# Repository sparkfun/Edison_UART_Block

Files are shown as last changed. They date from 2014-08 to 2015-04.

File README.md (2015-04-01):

SparkFun Edison UART Block
===========================

SparkFun Edison UART Block

[*SparkFun Edison UART Block(DEV-13040)*](https://www.sparkfun.com/products/13040)

The Console Basic expansion board delivers power to the Intel Edison while providing a simple console interface via a user's FTDI cable. This is the most minimal solution to get started using the Intel Edison. The Console Basic board can supply 4V and up to 500mA of current to power the Edison and any other expansion boards you may add to your stack. This power is passed through the VSYS line of the Edison.  This is a great board for low power applications that won't require constant console access.  By removing the FTDI USB-UART from the board, current consumption is minimal.  When the FTDI cable is not inserted, it will be necessary to provide external power to the board.

Repository Contents
------------------
* **/Hardware** - All Eagle design files (.brd, .sch)
* **/Production** -Test bed files and production panel files

License Information
------------------
The hardware is released under [Creative Commons ShareAlike 4.0 International](https://creativecommons.org/licenses/by-sa/4.0/).
The code is beerware; if you see me (or any other SparkFun employee) at the local, and you've found our code helpful, please buy us a round!

Distributed as-is; no warranty is given.

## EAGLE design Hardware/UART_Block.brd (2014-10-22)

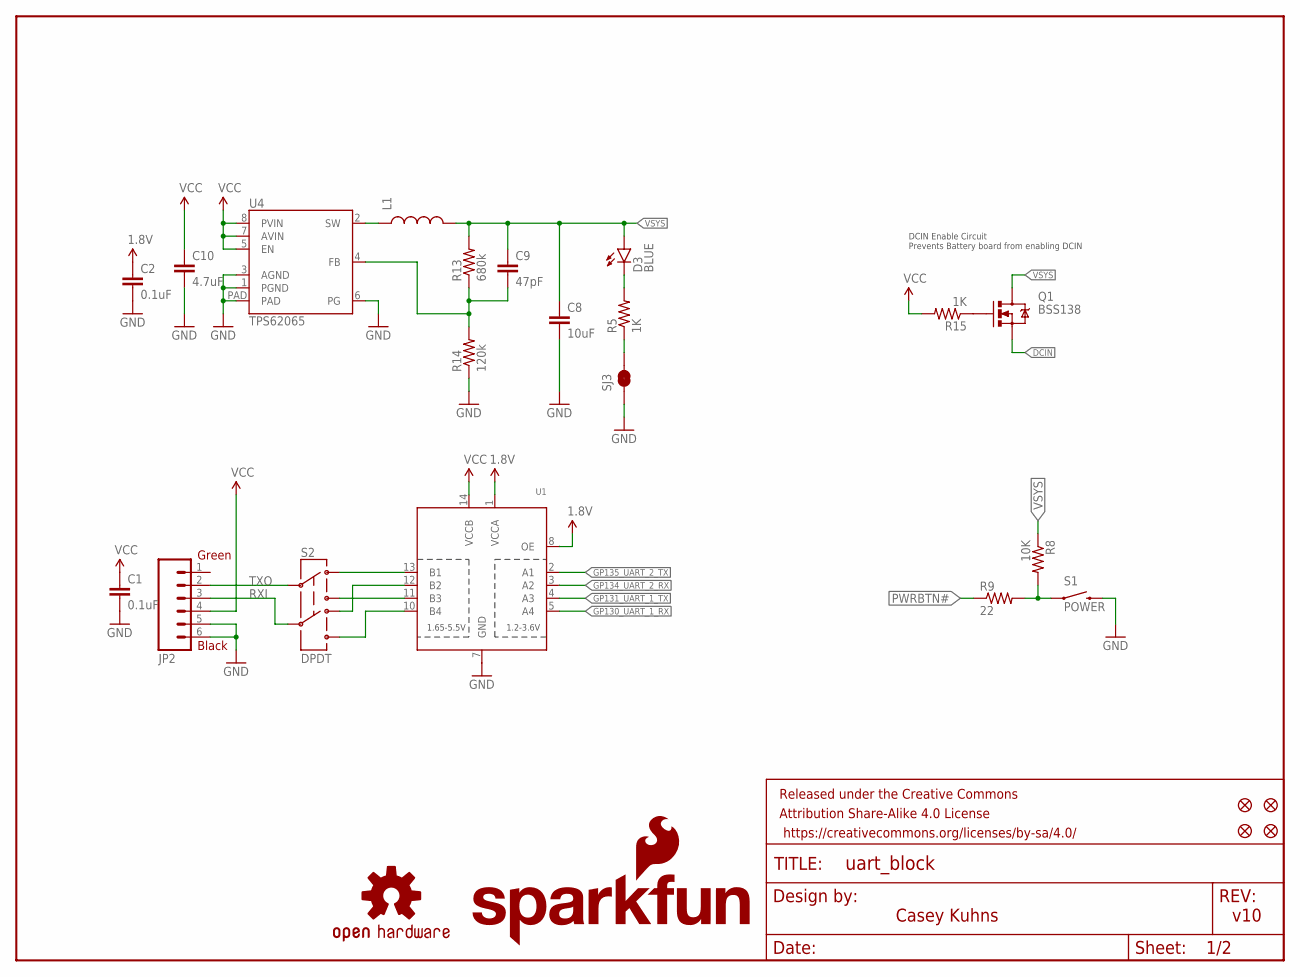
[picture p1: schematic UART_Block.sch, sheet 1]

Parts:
C1, C2: 0.1uF; 0603-CAP
C8: 10uF; 1206
C9: 47pF; 0603-CAP
C10: 4.7uF; 0603-CAP
D3: BLUE; LED-0603
FID1, FID2, FID3, FID4: FIDUCIAL1X2; FIDUCIAL-1X2
FRAME1: FRAME-LETTER; CREATIVE_COMMONS
JP2: M06SMD; 1X06-SMD
L1: INDUCTOR; INDUCTOR-SRP4020
LOGO1: SFE_LOGO_NAME_FLAME.1_INCH; SFE_LOGO_NAME_FLAME_.1
LOGO4: OSHW-LOGOS; OSHW-LOGO-S
Q1: BSS138; SOT23-3
R5, R15: 1K; 0603-RES
R8: 10K; 0603-RES
R9: 22; 0603-RES
R13: 680k; 0603-RES
R14: 120k; 0603-RES
S1: POWER; TACTILE_SWITCH-SMD-RIGHT-ANGLE
S2: DPDT; AYZ0202
SJ3: JUMPER-PAD-2-NC_BY_TRACE; PAD-JUMPER-2-NC_BY_TRACE_YES_SILK
U1: TXB0104PWRSOIC14; SO14
U4: TPS62065; WSON-8-PAD

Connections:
1.8V: C2.1, U1.1 (VCCA), U1.8 (OE); also elsewhere on the board
DCIN: Q1.2 (S); also elsewhere on the board
GND: C1.2, C2.2, C8.2, C10.2, JP2.5, JP2.6, R14.1, S1.2, SJ3.1, U1.7 (GND), U4.1 (PGND), U4.3 (AGND), U4.6 (PG), U4.PAD; also elsewhere on the board
GP130_UART_1_RX: U1.5 (A4); also elsewhere on the board
GP131_UART_1_TX: U1.4 (A3); also elsewhere on the board
GP134_UART_2_RX: U1.3 (A2); also elsewhere on the board
GP135_UART_2_TX: U1.2 (A1); also elsewhere on the board
unnamed: Q1.1 (G), R15.1
unnamed: D3.C, R5.2
unnamed: R5.1, SJ3.2
unnamed: R8.2, R9.2, S1.1
unnamed: C9.2, R13.1, R14.2, U4.4 (FB)
unnamed: L1.P$1 (1), U4.2 (SW)
PWRBTN#: R9.1; also elsewhere on the board
RXI: JP2.3, S2.5
TXO: JP2.2, S2.2
UART1RX: S2.6, U1.10 (B4)
UART1TX: S2.3, U1.11 (B3)
UART2RX: S2.4, U1.12 (B2)
UART2TX: S2.1, U1.13 (B1)
VCC: C1.1, C10.1, JP2.4, R15.2, U1.14 (VCCB), U4.5 (EN), U4.7 (AVIN), U4.8 (PVIN)
VSYS: C8.1, C9.1, D3.A, L1.P$2 (2), Q1.3 (D), R8.1, R13.2; also elsewhere on the board

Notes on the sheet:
Black
Green
v10
Casey Kuhns
DCIN Enable Circuit Prevents Battery board from enabling DCIN

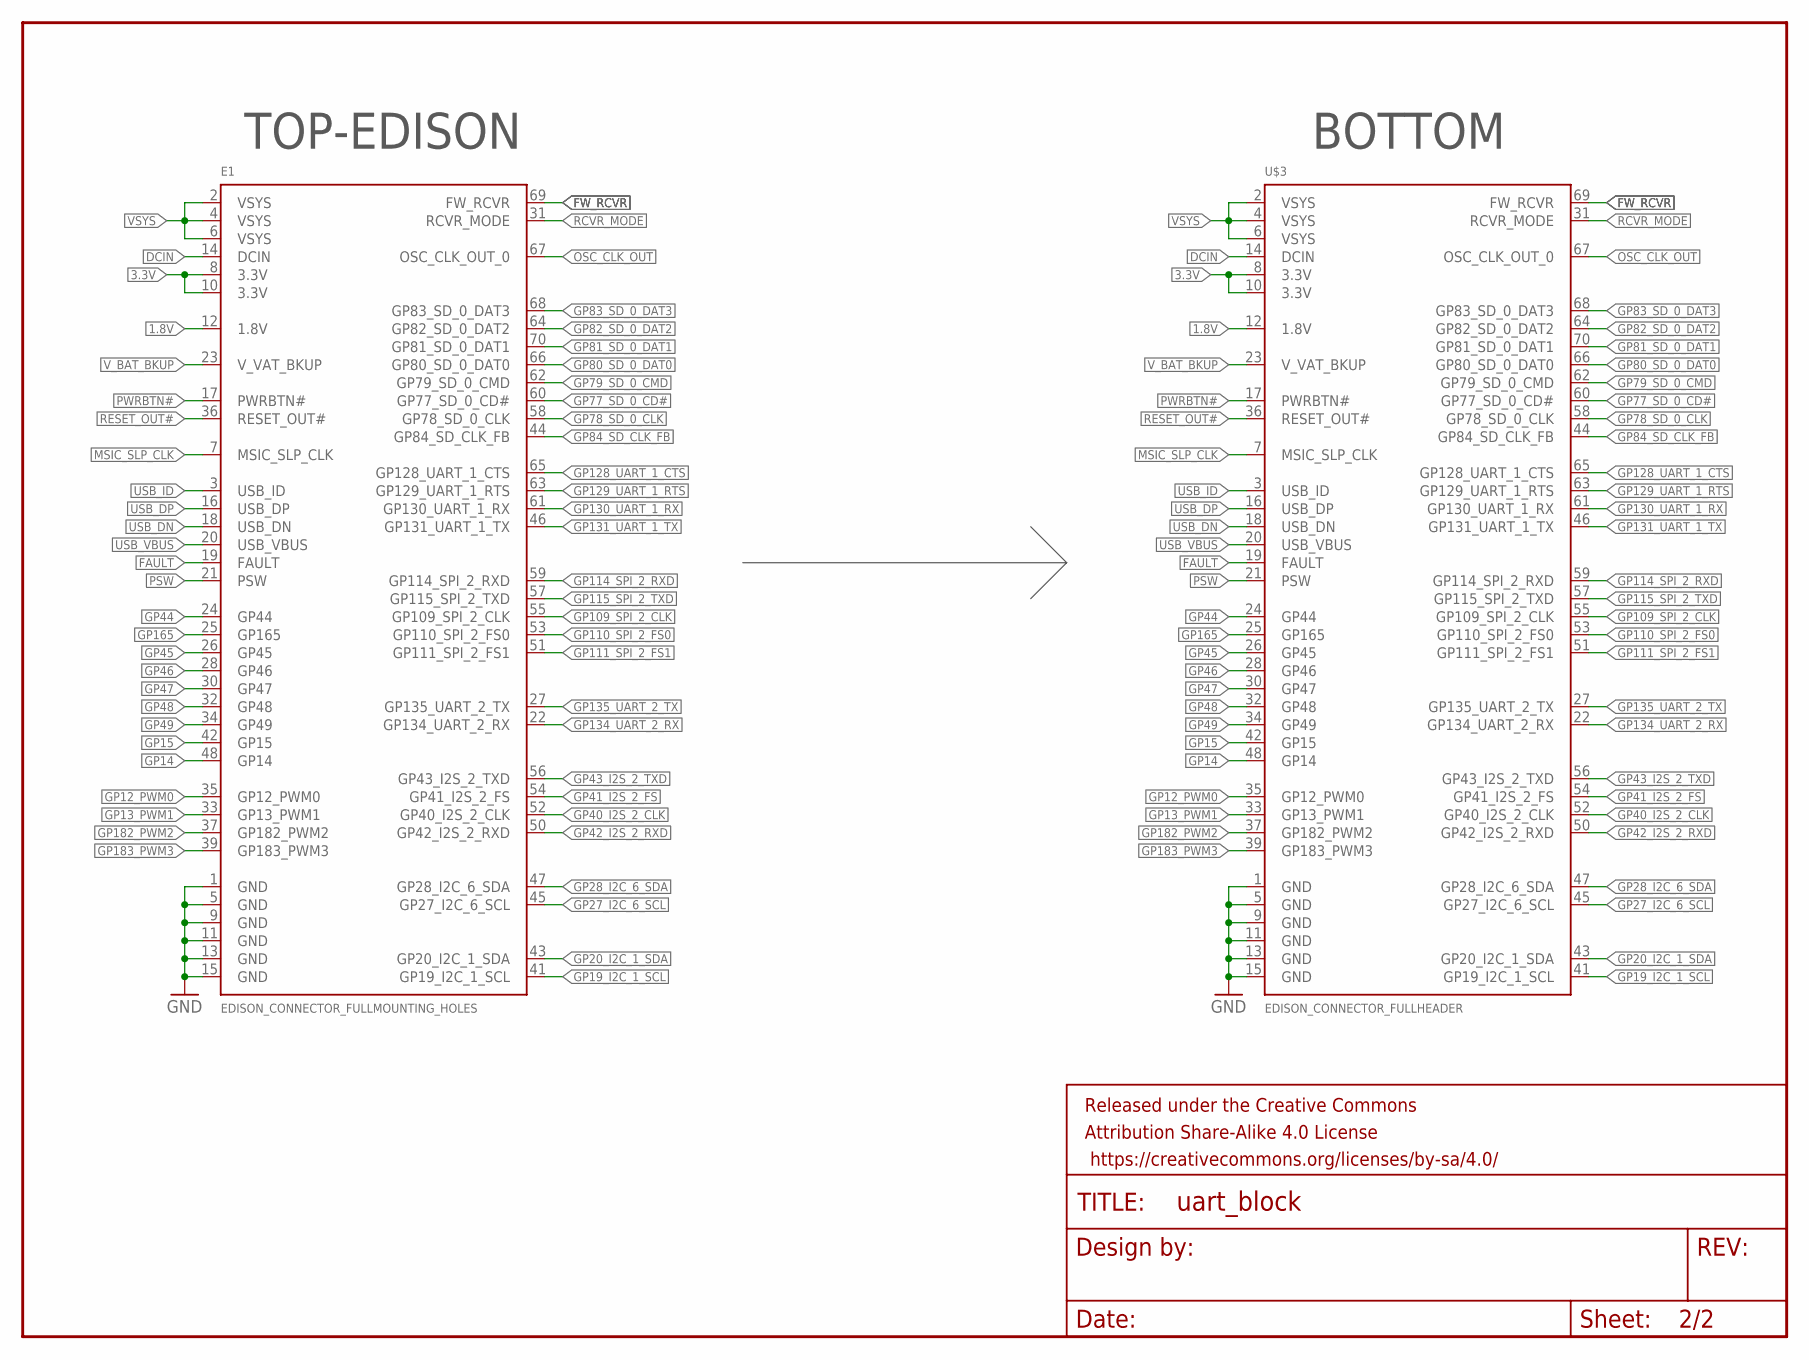
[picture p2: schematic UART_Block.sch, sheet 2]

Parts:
E1: EDISON_CONNECTOR_FULLMOUNTING_HOLES; EDISON_DAUGHTER
FRAME2: FRAME-LETTER; CREATIVE_COMMONS
U$3: EDISON_CONNECTOR_FULLHEADER; DF40C-70DP-0.4(51)

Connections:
1.8V: E1.12 (1.8V), U$3.12 (1.8V); also elsewhere on the board
3.3V: E1.8 (3.3V), E1.10 (3.3V), U$3.8 (3.3V), U$3.10 (3.3V)
DCIN: E1.14 (DCIN), U$3.14 (DCIN); also elsewhere on the board
FAULT: E1.19 (FAULT), U$3.19 (FAULT)
FW_RCVR: E1.69 (FW_RCVR), U$3.69 (FW_RCVR)
GND: E1.1 (GND), E1.5 (GND), E1.9 (GND), E1.11 (GND), E1.13 (GND), E1.15 (GND), U$3.1 (GND), U$3.5 (GND), U$3.9 (GND), U$3.11 (GND), U$3.13 (GND), U$3.15 (GND); also elsewhere on the board
GP12_PWM0: E1.35 (GP12_PWM0), U$3.35 (GP12_PWM0)
GP13_PWM1: E1.33 (GP13_PWM1), U$3.33 (GP13_PWM1)
GP14: E1.48 (GP14), U$3.48 (GP14)
GP15: E1.42 (GP15), U$3.42 (GP15)
GP19_I2C_1_SCL: E1.41 (GP19_I2C_1_SCL), U$3.41 (GP19_I2C_1_SCL)
GP20_I2C_1_SDA: E1.43 (GP20_I2C_1_SDA), U$3.43 (GP20_I2C_1_SDA)
GP27_I2C_6_SCL: E1.45 (GP27_I2C_6_SCL), U$3.45 (GP27_I2C_6_SCL)
GP28_I2C_6_SDA: E1.47 (GP28_I2C_6_SDA), U$3.47 (GP28_I2C_6_SDA)
GP40_I2S_2_CLK: E1.52 (GP40_I2S_2_CLK), U$3.52 (GP40_I2S_2_CLK)
GP41_I2S_2_FS: E1.54 (GP41_I2S_2_FS), U$3.54 (GP41_I2S_2_FS)
GP42_I2S_2_RXD: E1.50 (GP42_I2S_2_RXD), U$3.50 (GP42_I2S_2_RXD)
GP43_I2S_2_TXD: E1.56 (GP43_I2S_2_TXD), U$3.56 (GP43_I2S_2_TXD)
GP44: E1.24 (GP44), U$3.24 (GP44)
GP45: E1.26 (GP45), U$3.26 (GP45)
GP46: E1.28 (GP46), U$3.28 (GP46)
GP47: E1.30 (GP47), U$3.30 (GP47)
GP48: E1.32 (GP48), U$3.32 (GP48)
GP49: E1.34 (GP49), U$3.34 (GP49)
GP77_SD_0_CD#: E1.60 (GP77_SD_0_CD#), U$3.60 (GP77_SD_0_CD#)
GP78_SD_0_CLK: E1.58 (GP78_SD_0_CLK), U$3.58 (GP78_SD_0_CLK)
GP79_SD_0_CMD: E1.62 (GP79_SD_0_CMD), U$3.62 (GP79_SD_0_CMD)
GP80_SD_0_DAT0: E1.66 (GP80_SD_0_DAT0), U$3.66 (GP80_SD_0_DAT0)
GP81_SD_0_DAT1: E1.70 (GP81_SD_0_DAT1), U$3.70 (GP81_SD_0_DAT1)
GP82_SD_0_DAT2: E1.64 (GP82_SD_0_DAT2), U$3.64 (GP82_SD_0_DAT2)
GP83_SD_0_DAT3: E1.68 (GP83_SD_0_DAT3), U$3.68 (GP83_SD_0_DAT3)
GP84_SD_CLK_FB: E1.44 (GP84_SD_CLK_FB), U$3.44 (GP84_SD_CLK_FB)
GP109_SPI_2_CLK: E1.55 (GP109_SPI_2_CLK), U$3.55 (GP109_SPI_2_CLK)
GP110_SPI_2_FS0: E1.53 (GP110_SPI_2_FS0), U$3.53 (GP110_SPI_2_FS0)
GP111_SPI_2_FS1: E1.51 (GP111_SPI_2_FS1), U$3.51 (GP111_SPI_2_FS1)
GP114_SPI_2_RXD: E1.59 (GP114_SPI_2_RXD), U$3.59 (GP114_SPI_2_RXD)
GP115_SPI_2_TXD: E1.57 (GP115_SPI_2_TXD), U$3.57 (GP115_SPI_2_TXD)
GP128_UART_1_CTS: E1.65 (GP128_UART_1_CTS), U$3.65 (GP128_UART_1_CTS)
GP129_UART_1_RTS: E1.63 (GP129_UART_1_RTS), U$3.63 (GP129_UART_1_RTS)
GP130_UART_1_RX: E1.61 (GP130_UART_1_RX), U$3.61 (GP130_UART_1_RX); also elsewhere on the board
GP131_UART_1_TX: E1.46 (GP131_UART_1_TX), U$3.46 (GP131_UART_1_TX); also elsewhere on the board
GP134_UART_2_RX: E1.22 (GP134_UART_2_RX), U$3.22 (GP134_UART_2_RX); also elsewhere on the board
GP135_UART_2_TX: E1.27 (GP135_UART_2_TX), U$3.27 (GP135_UART_2_TX); also elsewhere on the board
GP165: E1.25 (GP165), U$3.25 (GP165)
GP182_PWM2: E1.37 (GP182_PWM2), U$3.37 (GP182_PWM2)
GP183_PWM3: E1.39 (GP183_PWM3), U$3.39 (GP183_PWM3)
MSIC_SLP_CLK: E1.7 (MSIC_SLP_CLK), U$3.7 (MSIC_SLP_CLK)
OSC_CLK_OUT: E1.67 (OSC_CLK_OUT_0), U$3.67 (OSC_CLK_OUT_0)
PSW: E1.21 (PSW), U$3.21 (PSW)
PWRBTN#: E1.17 (PWRBTN#), U$3.17 (PWRBTN#); also elsewhere on the board
RCVR_MODE: E1.31 (RCVR_MODE), U$3.31 (RCVR_MODE)
RESET_OUT#: E1.36 (RESET_OUT#), U$3.36 (RESET_OUT#)
USB_DN: E1.18 (USB_DN), U$3.18 (USB_DN)
USB_DP: E1.16 (USB_DP), U$3.16 (USB_DP)
USB_ID: E1.3 (USB_ID), U$3.3 (USB_ID)
USB_VBUS: E1.20 (USB_VBUS), U$3.20 (USB_VBUS)
VSYS: E1.2 (VSYS), E1.4 (VSYS), E1.6 (VSYS), U$3.2 (VSYS), U$3.4 (VSYS), U$3.6 (VSYS); also elsewhere on the board
V_BAT_BKUP: E1.23 (V_VAT_BKUP), U$3.23 (V_VAT_BKUP)

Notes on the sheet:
TOP-EDISON
BOTTOM

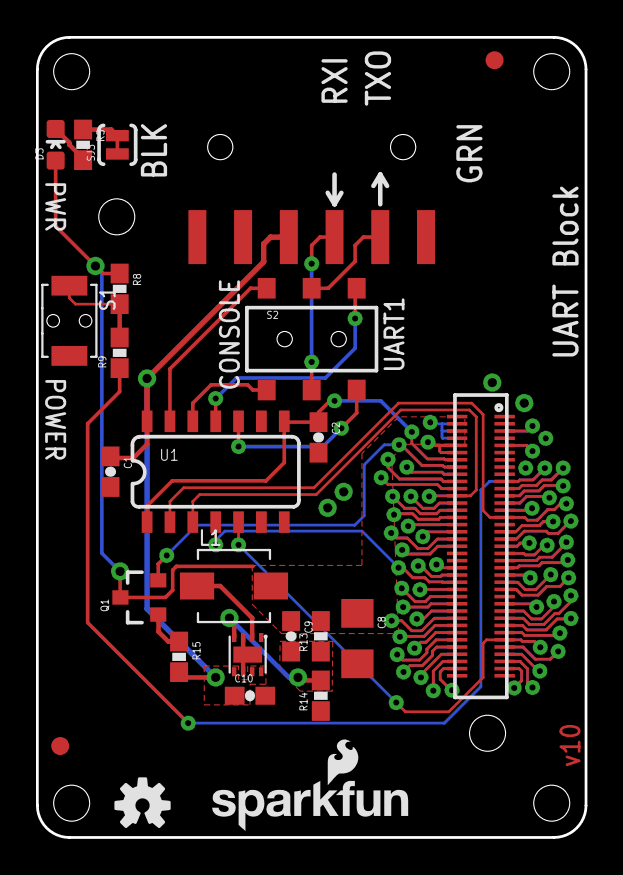
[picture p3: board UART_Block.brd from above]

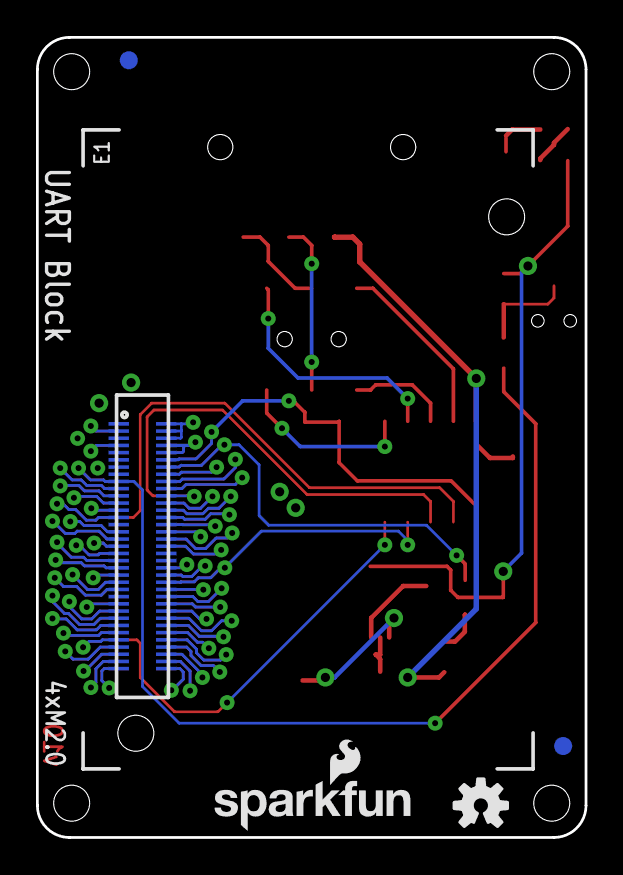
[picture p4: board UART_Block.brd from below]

Board: 2 copper layers, 30.5 x 44.5 mm, 32 parts (6 on the bottom side), 71 nets.

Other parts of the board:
LOGO2: OSHW-LOGOS; OSHW-LOGO-S
LOGO3: SFE_LOGO_NAME_FLAME.1_INCH; SFE_LOGO_NAME_FLAME_.1

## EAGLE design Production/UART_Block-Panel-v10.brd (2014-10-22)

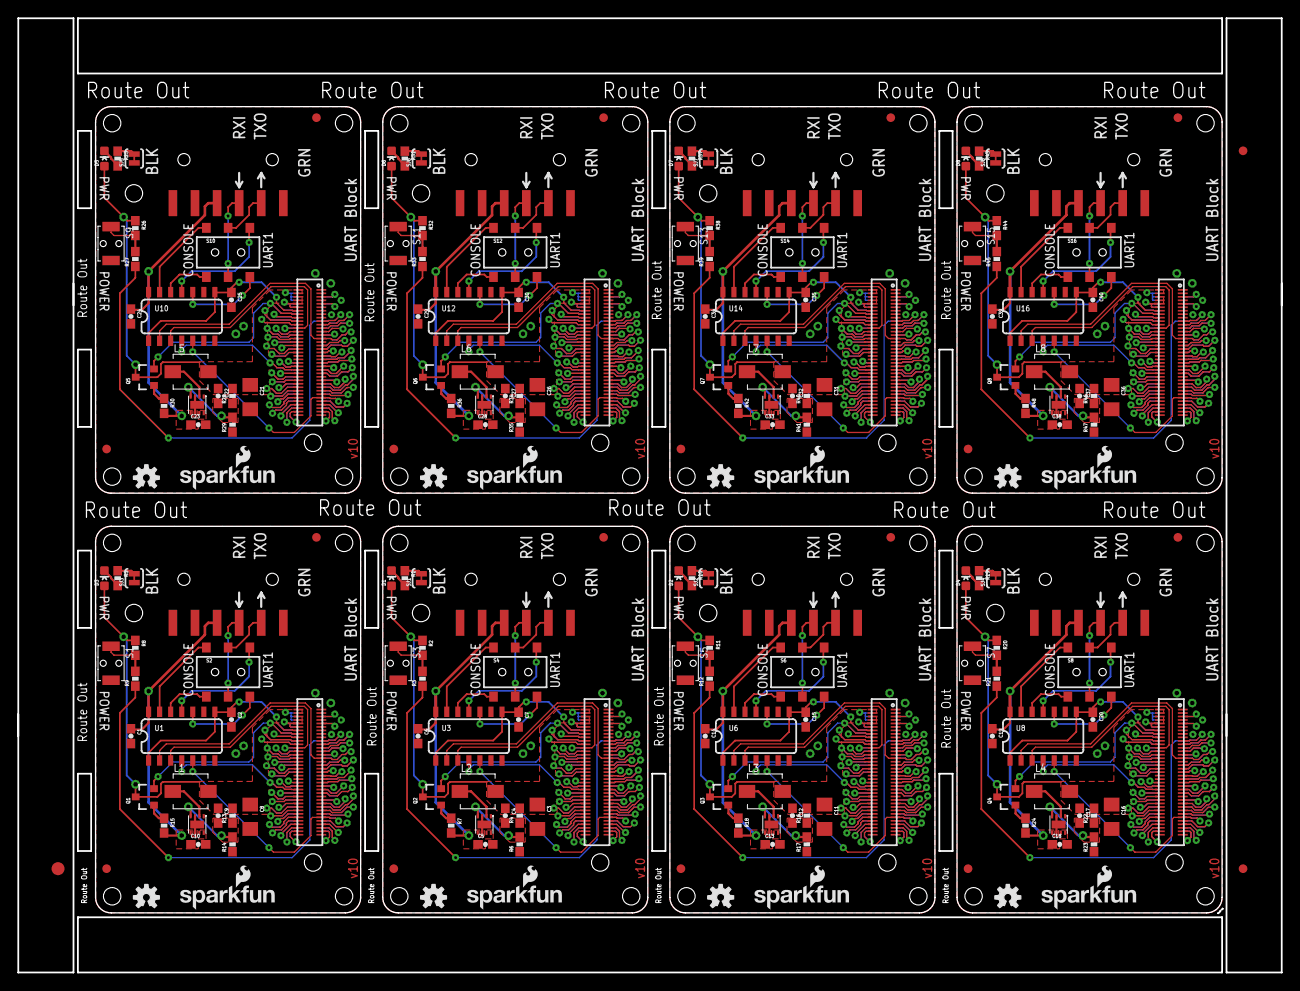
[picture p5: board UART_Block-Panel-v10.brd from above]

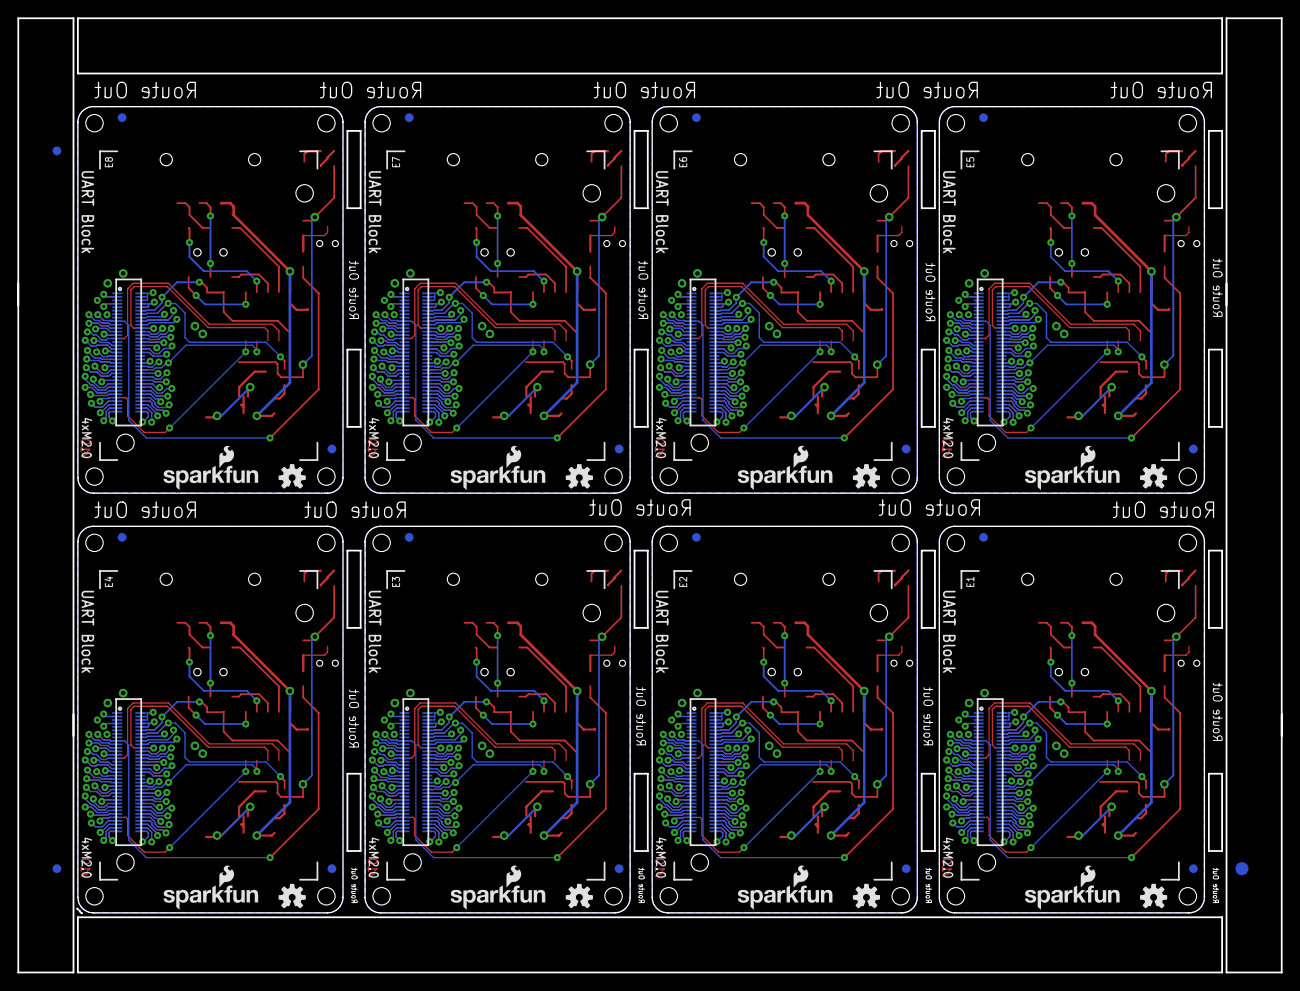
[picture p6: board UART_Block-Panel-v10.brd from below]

Board: 2 copper layers, 145.3 x 109.7 mm, 246 parts (51 on the bottom side), 568 nets.

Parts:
C1, C2, C6, C7, C14, C15, C19, C20, C24, C25, C29, C30, C34, C35, C39, C40: 0.1uF; 0603-CAP
C3, C8, C11, C16, C21, C26, C31, C36: 10uF; 1206
C4, C9, C12, C17, C22, C27, C32, C37: 47pF; 0603-CAP
C5, C10, C13, C18, C23, C28, C33, C38: 4.7uF; 0603-CAP
D1, D2, D3, D4, D5, D6, D7, D8: BLUE; LED-0603
E1, E2, E3, E4, E5, E6, E7, E8: EDISON_CONNECTOR_FULLMOUNTING_HOLES; EDISON_DAUGHTER
E$1, E$2: FIDUCIAL-1.5X3
E$3, E$4, E$5, E$6: FIDUCIAL-1X2
FID1, FID2, FID3, FID4, FID5, FID6, FID7, FID8, FID9, FID10, FID11, FID12, FID13, FID14, FID15, FID16, FID17, FID18, FID19, FID20, FID21, FID22, FID23, FID24, FID25, FID26, FID27, FID28, FID29, FID30, FID31, FID32: FIDUCIAL1X2; FIDUCIAL-1X2
JP1, JP2, JP3, JP4, JP5, JP6, JP7, JP8: 1X06-SMD
L1, L2, L3, L4, L5, L6, L7, L8: INDUCTOR-SRP4020
LOGO1, LOGO3, LOGO6, LOGO7, LOGO10, LOGO11, LOGO14, LOGO15, LOGO18, LOGO19, LOGO22, LOGO23, LOGO26, LOGO27, LOGO30, LOGO31: SFE_LOGO_NAME_FLAME.1_INCH; SFE_LOGO_NAME_FLAME_.1
LOGO2, LOGO4, LOGO5, LOGO8, LOGO9, LOGO12, LOGO13, LOGO16, LOGO17, LOGO20, LOGO21, LOGO24, LOGO25, LOGO28, LOGO29, LOGO32: OSHW-LOGOS; OSHW-LOGO-S
Q1, Q2, Q3, Q4, Q5, Q6, Q7, Q8: BSS138; SOT23-3
R1, R5, R7, R10, R15, R18, R19, R24, R25, R30, R31, R36, R37, R42, R43, R48: 1K; 0603-RES
R2, R8, R11, R20, R26, R32, R38, R44: 10K; 0603-RES
R3, R9, R12, R21, R27, R33, R39, R45: 22; 0603-RES
R4, R13, R16, R22, R28, R34, R40, R46: 680k; 0603-RES
R6, R14, R17, R23, R29, R35, R41, R47: 120k; 0603-RES
S1, S3, S5, S7, S9, S11, S13, S15: POWER; TACTILE_SWITCH-SMD-RIGHT-ANGLE
S2, S4, S6, S8, S10, S12, S14, S16: DPDT; AYZ0202
SJ1, SJ2, SJ3, SJ4, SJ5, SJ6, SJ7, SJ8: JUMPER-PAD-2-NC_BY_TRACE; PAD-JUMPER-2-NC_BY_TRACE_YES_SILK
U1, U3, U6, U8, U10, U12, U14, U16: SO14
U2, U4, U5, U7, U9, U11, U13, U15: TPS62065; WSON-8-PAD
U$1, U$2, U$3, U$4, U$5, U$6, U$7, U$8: EDISON_CONNECTOR_FULLHEADER; DF40C-70DP-0.4(51)

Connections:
1.8V: C2.1, E1.12, U1.1, U1.8, U$3.12
1.8V1: C7.1, E2.12, U3.1, U3.8, U$1.12
1.8V2: C15.1, E3.12, U6.1, U6.8, U$2.12
1.8V3: C20.1, E4.12, U8.1, U8.8, U$4.12
1.8V4: C25.1, E5.12, U10.1, U10.8, U$5.12
1.8V5: C30.1, E6.12, U12.1, U12.8, U$6.12
1.8V6: C35.1, E7.12, U14.1, U14.8, U$7.12
1.8V7: C40.1, E8.12, U16.1, U16.8, U$8.12
3.3V: E1.8, E1.10, U$3.8, U$3.10
3.3V1: E2.8, E2.10, U$1.8, U$1.10
3.3V2: E3.8, E3.10, U$2.8, U$2.10
3.3V3: E4.8, E4.10, U$4.8, U$4.10
3.3V4: E5.8, E5.10, U$5.8, U$5.10
3.3V5: E6.8, E6.10, U$6.8, U$6.10
3.3V6: E7.8, E7.10, U$7.8, U$7.10
3.3V7: E8.8, E8.10, U$8.8, U$8.10
DCIN: E1.14, Q1.2, U$3.14
DCIN1: E2.14, Q2.2, U$1.14
DCIN2: E3.14, Q3.2, U$2.14
DCIN3: E4.14, Q4.2, U$4.14
DCIN4: E5.14, Q5.2, U$5.14
DCIN5: E6.14, Q6.2, U$6.14
DCIN6: E7.14, Q7.2, U$7.14
DCIN7: E8.14, Q8.2, U$8.14
FAULT: E1.19, U$3.19
FAULT1: E2.19, U$1.19
FAULT2: E3.19, U$2.19
FAULT3: E4.19, U$4.19
FAULT4: E5.19, U$5.19
FAULT5: E6.19, U$6.19
FAULT6: E7.19, U$7.19
FAULT7: E8.19, U$8.19
FW_RCVR: E1.69, U$3.69
FW_RCVR1: E2.69, U$1.69
FW_RCVR2: E3.69, U$2.69
FW_RCVR3: E4.69, U$4.69
FW_RCVR4: E5.69, U$5.69
FW_RCVR5: E6.69, U$6.69
FW_RCVR6: E7.69, U$7.69
FW_RCVR7: E8.69, U$8.69
GND: C1.2, C2.2, C8.2, C10.2, E1.1, E1.5, E1.9, E1.11, E1.13, E1.15, JP2.5, JP2.6, R14.1, S1.2, SJ3.1, U1.7, U4.1, U4.3, U4.6, U4.PAD, U$3.1, U$3.5, U$3.9, U$3.11, U$3.13, U$3.15
GND1: C3.2, C5.2, C6.2, C7.2, E2.1, E2.5, E2.9, E2.11, E2.13, E2.15, JP1.5, JP1.6, R6.1, S3.2, SJ1.1, U2.1, U2.3, U2.6, U2.PAD, U3.7, U$1.1, U$1.5, U$1.9, U$1.11, U$1.13, U$1.15
GND2: C11.2, C13.2, C14.2, C15.2, E3.1, E3.5, E3.9, E3.11, E3.13, E3.15, JP3.5, JP3.6, R17.1, S5.2, SJ2.1, U5.1, U5.3, U5.6, U5.PAD, U6.7, U$2.1, U$2.5, U$2.9, U$2.11, U$2.13, U$2.15
GND3: C16.2, C18.2, C19.2, C20.2, E4.1, E4.5, E4.9, E4.11, E4.13, E4.15, JP4.5, JP4.6, R23.1, S7.2, SJ4.1, U7.1, U7.3, U7.6, U7.PAD, U8.7, U$4.1, U$4.5, U$4.9, U$4.11, U$4.13, U$4.15
GND4: C21.2, C23.2, C24.2, C25.2, E5.1, E5.5, E5.9, E5.11, E5.13, E5.15, JP5.5, JP5.6, R29.1, S9.2, SJ5.1, U9.1, U9.3, U9.6, U9.PAD, U10.7, U$5.1, U$5.5, U$5.9, U$5.11, U$5.13, U$5.15
GND5: C26.2, C28.2, C29.2, C30.2, E6.1, E6.5, E6.9, E6.11, E6.13, E6.15, JP6.5, JP6.6, R35.1, S11.2, SJ6.1, U11.1, U11.3, U11.6, U11.PAD, U12.7, U$6.1, U$6.5, U$6.9, U$6.11, U$6.13, U$6.15
GND6: C31.2, C33.2, C34.2, C35.2, E7.1, E7.5, E7.9, E7.11, E7.13, E7.15, JP7.5, JP7.6, R41.1, S13.2, SJ7.1, U13.1, U13.3, U13.6, U13.PAD, U14.7, U$7.1, U$7.5, U$7.9, U$7.11, U$7.13, U$7.15
GND7: C36.2, C38.2, C39.2, C40.2, E8.1, E8.5, E8.9, E8.11, E8.13, E8.15, JP8.5, JP8.6, R47.1, S15.2, SJ8.1, U15.1, U15.3, U15.6, U15.PAD, U16.7, U$8.1, U$8.5, U$8.9, U$8.11, U$8.13, U$8.15
GP1: E2.48, U$1.48
GP2: E2.42, U$1.42
GP3: E2.34, U$1.34
GP4: E2.32, U$1.32
GP5: E2.30, U$1.30
GP6: E2.28, U$1.28
GP7: E2.26, U$1.26
GP8: E2.25, U$1.25
GP9: E2.24, U$1.24
GP10: E3.48, U$2.48
GP11: E3.42, U$2.42
GP12: E3.34, U$2.34
GP12_PWM0: E1.35, U$3.35
GP12_PWM1: E2.35, U$1.35
GP12_PWM2: E3.35, U$2.35
GP12_PWM3: E4.35, U$4.35
GP12_PWM4: E5.35, U$5.35
GP12_PWM5: E6.35, U$6.35
GP12_PWM6: E7.35, U$7.35
GP12_PWM7: E8.35, U$8.35
GP13: E3.32, U$2.32
GP13_PWM1: E1.33, U$3.33
GP13_PWM2: E2.33, U$1.33
GP13_PWM3: E3.33, U$2.33
GP13_PWM4: E4.33, U$4.33
GP13_PWM5: E5.33, U$5.33
GP13_PWM6: E6.33, U$6.33
GP13_PWM7: E7.33, U$7.33
GP13_PWM8: E8.33, U$8.33
GP14: E1.48, U$3.48
GP15: E1.42, U$3.42
GP16: E3.30, U$2.30
GP17: E3.28, U$2.28
GP18: E3.26, U$2.26
GP19: E3.25, U$2.25
GP19_I2C_1_SCL: E1.41, U$3.41
GP19_I2C_1_SCL1: E2.41, U$1.41
GP19_I2C_1_SCL2: E3.41, U$2.41
GP19_I2C_1_SCL3: E4.41, U$4.41
GP19_I2C_1_SCL4: E5.41, U$5.41
GP19_I2C_1_SCL5: E6.41, U$6.41
GP19_I2C_1_SCL6: E7.41, U$7.41
GP19_I2C_1_SCL7: E8.41, U$8.41
GP20: E3.24, U$2.24
GP20_I2C_1_SDA: E1.43, U$3.43
GP20_I2C_1_SDA1: E2.43, U$1.43
GP20_I2C_1_SDA2: E3.43, U$2.43
GP20_I2C_1_SDA3: E4.43, U$4.43
GP20_I2C_1_SDA4: E5.43, U$5.43
GP20_I2C_1_SDA5: E6.43, U$6.43
GP20_I2C_1_SDA6: E7.43, U$7.43
GP20_I2C_1_SDA7: E8.43, U$8.43
GP21: E4.48, U$4.48
GP22: E4.42, U$4.42
GP23: E4.34, U$4.34
GP24: E4.32, U$4.32
GP25: E4.30, U$4.30
GP26: E4.28, U$4.28
GP27: E4.26, U$4.26
GP27_I2C_6_SCL: E1.45, U$3.45
GP27_I2C_6_SCL1: E2.45, U$1.45
GP27_I2C_6_SCL2: E3.45, U$2.45
GP27_I2C_6_SCL3: E4.45, U$4.45
GP27_I2C_6_SCL4: E5.45, U$5.45
GP27_I2C_6_SCL5: E6.45, U$6.45
GP27_I2C_6_SCL6: E7.45, U$7.45
GP27_I2C_6_SCL7: E8.45, U$8.45
GP28: E4.25, U$4.25
GP28_I2C_6_SDA: E1.47, U$3.47
GP28_I2C_6_SDA1: E2.47, U$1.47
GP28_I2C_6_SDA2: E3.47, U$2.47
GP28_I2C_6_SDA3: E4.47, U$4.47
GP28_I2C_6_SDA4: E5.47, U$5.47
GP28_I2C_6_SDA5: E6.47, U$6.47
GP28_I2C_6_SDA6: E7.47, U$7.47
GP28_I2C_6_SDA7: E8.47, U$8.47
GP29: E4.24, U$4.24
GP30: E5.48, U$5.48
GP31: E5.42, U$5.42
GP32: E5.34, U$5.34
GP33: E5.32, U$5.32
GP34: E5.30, U$5.30
GP35: E5.28, U$5.28
GP36: E5.26, U$5.26
GP37: E5.25, U$5.25
GP38: E5.24, U$5.24
GP39: E6.48, U$6.48
GP40: E6.42, U$6.42
GP40_I2S_2_CLK: E1.52, U$3.52
GP40_I2S_2_CLK1: E2.52, U$1.52
GP40_I2S_2_CLK2: E3.52, U$2.52
GP40_I2S_2_CLK3: E4.52, U$4.52
GP40_I2S_2_CLK4: E5.52, U$5.52
GP40_I2S_2_CLK5: E6.52, U$6.52
GP40_I2S_2_CLK6: E7.52, U$7.52
GP40_I2S_2_CLK7: E8.52, U$8.52
GP41: E6.34, U$6.34
GP41_I2S_2_FS: E1.54, U$3.54
GP41_I2S_2_FS1: E2.54, U$1.54
GP41_I2S_2_FS2: E3.54, U$2.54
GP41_I2S_2_FS3: E4.54, U$4.54
GP41_I2S_2_FS4: E5.54, U$5.54
GP41_I2S_2_FS5: E6.54, U$6.54
GP41_I2S_2_FS6: E7.54, U$7.54
GP41_I2S_2_FS7: E8.54, U$8.54
GP42: E6.32, U$6.32
GP42_I2S_2_RXD: E1.50, U$3.50
GP42_I2S_2_RXD1: E2.50, U$1.50
GP42_I2S_2_RXD2: E3.50, U$2.50
GP42_I2S_2_RXD3: E4.50, U$4.50
GP42_I2S_2_RXD4: E5.50, U$5.50
GP42_I2S_2_RXD5: E6.50, U$6.50
GP42_I2S_2_RXD6: E7.50, U$7.50
GP42_I2S_2_RXD7: E8.50, U$8.50
GP43: E6.30, U$6.30
GP43_I2S_2_TXD: E1.56, U$3.56
GP43_I2S_2_TXD1: E2.56, U$1.56
GP43_I2S_2_TXD2: E3.56, U$2.56
GP43_I2S_2_TXD3: E4.56, U$4.56
GP43_I2S_2_TXD4: E5.56, U$5.56
GP43_I2S_2_TXD5: E6.56, U$6.56
GP43_I2S_2_TXD6: E7.56, U$7.56
GP43_I2S_2_TXD7: E8.56, U$8.56
GP44: E1.24, U$3.24
GP45: E1.26, U$3.26
GP46: E1.28, U$3.28
GP47: E1.30, U$3.30
GP48: E1.32, U$3.32
GP49: E1.34, U$3.34
GP50: E6.28, U$6.28
GP51: E6.26, U$6.26
GP52: E6.25, U$6.25
GP53: E6.24, U$6.24
GP54: E7.48, U$7.48
GP55: E7.42, U$7.42
GP56: E7.34, U$7.34
GP57: E7.32, U$7.32
GP58: E7.30, U$7.30
GP59: E7.28, U$7.28
GP60: E7.26, U$7.26
GP61: E7.25, U$7.25
GP62: E7.24, U$7.24
GP63: E8.48, U$8.48
GP64: E8.42, U$8.42
GP65: E8.34, U$8.34
GP66: E8.32, U$8.32
GP67: E8.30, U$8.30
GP68: E8.28, U$8.28
GP69: E8.26, U$8.26
GP70: E8.25, U$8.25
GP71: E8.24, U$8.24
GP77_SD_0_CD#: E1.60, U$3.60
GP77_SD_0_CD#1: E2.60, U$1.60
GP77_SD_0_CD#2: E3.60, U$2.60
GP77_SD_0_CD#3: E4.60, U$4.60
GP77_SD_0_CD#4: E5.60, U$5.60
GP77_SD_0_CD#5: E6.60, U$6.60
GP77_SD_0_CD#6: E7.60, U$7.60
GP77_SD_0_CD#7: E8.60, U$8.60
GP78_SD_0_CLK: E1.58, U$3.58
GP78_SD_0_CLK1: E2.58, U$1.58
GP78_SD_0_CLK2: E3.58, U$2.58
GP78_SD_0_CLK3: E4.58, U$4.58
GP78_SD_0_CLK4: E5.58, U$5.58
GP78_SD_0_CLK5: E6.58, U$6.58
GP78_SD_0_CLK6: E7.58, U$7.58
GP78_SD_0_CLK7: E8.58, U$8.58
GP79_SD_0_CMD: E1.62, U$3.62
GP79_SD_0_CMD1: E2.62, U$1.62
GP79_SD_0_CMD2: E3.62, U$2.62
GP79_SD_0_CMD3: E4.62, U$4.62
GP79_SD_0_CMD4: E5.62, U$5.62
GP79_SD_0_CMD5: E6.62, U$6.62
GP79_SD_0_CMD6: E7.62, U$7.62
GP79_SD_0_CMD7: E8.62, U$8.62
GP80_SD_0_DAT0: E1.66, U$3.66
GP80_SD_0_DAT1: E2.66, U$1.66
GP80_SD_0_DAT2: E3.66, U$2.66
GP80_SD_0_DAT3: E4.66, U$4.66
GP80_SD_0_DAT4: E5.66, U$5.66
GP80_SD_0_DAT5: E6.66, U$6.66
GP80_SD_0_DAT6: E7.66, U$7.66
GP80_SD_0_DAT7: E8.66, U$8.66
GP81_SD_0_DAT1: E1.70, U$3.70
GP81_SD_0_DAT2: E2.70, U$1.70
GP81_SD_0_DAT3: E3.70, U$2.70
GP81_SD_0_DAT4: E4.70, U$4.70
GP81_SD_0_DAT5: E5.70, U$5.70
GP81_SD_0_DAT6: E6.70, U$6.70
GP81_SD_0_DAT7: E7.70, U$7.70
GP81_SD_0_DAT8: E8.70, U$8.70
GP82_SD_0_DAT1: E2.64, U$1.64
GP82_SD_0_DAT2: E1.64, U$3.64
GP82_SD_0_DAT3: E3.64, U$2.64
GP82_SD_0_DAT4: E4.64, U$4.64
GP82_SD_0_DAT5: E5.64, U$5.64
GP82_SD_0_DAT6: E6.64, U$6.64
GP82_SD_0_DAT7: E7.64, U$7.64
GP82_SD_0_DAT8: E8.64, U$8.64
GP83_SD_0_DAT1: E2.68, U$1.68
GP83_SD_0_DAT2: E3.68, U$2.68
GP83_SD_0_DAT3: E1.68, U$3.68
GP83_SD_0_DAT4: E4.68, U$4.68
GP83_SD_0_DAT5: E5.68, U$5.68
GP83_SD_0_DAT6: E6.68, U$6.68
GP83_SD_0_DAT7: E7.68, U$7.68
GP83_SD_0_DAT8: E8.68, U$8.68
GP84_SD_CLK_FB: E1.44, U$3.44
GP84_SD_CLK_FB1: E2.44, U$1.44
GP84_SD_CLK_FB2: E3.44, U$2.44
GP84_SD_CLK_FB3: E4.44, U$4.44
GP84_SD_CLK_FB4: E5.44, U$5.44
GP84_SD_CLK_FB5: E6.44, U$6.44
GP84_SD_CLK_FB6: E7.44, U$7.44
GP84_SD_CLK_FB7: E8.44, U$8.44
GP109_SPI_2_CLK: E1.55, U$3.55
GP109_SPI_2_CLK1: E2.55, U$1.55
GP109_SPI_2_CLK2: E3.55, U$2.55
GP109_SPI_2_CLK3: E4.55, U$4.55
GP109_SPI_2_CLK4: E5.55, U$5.55
GP109_SPI_2_CLK5: E6.55, U$6.55
GP109_SPI_2_CLK6: E7.55, U$7.55
GP109_SPI_2_CLK7: E8.55, U$8.55
GP110_SPI_2_FS0: E1.53, U$3.53
GP110_SPI_2_FS1: E2.53, U$1.53
GP110_SPI_2_FS2: E3.53, U$2.53
GP110_SPI_2_FS3: E4.53, U$4.53
GP110_SPI_2_FS4: E5.53, U$5.53
GP110_SPI_2_FS5: E6.53, U$6.53
GP110_SPI_2_FS6: E7.53, U$7.53
GP110_SPI_2_FS7: E8.53, U$8.53
GP111_SPI_2_FS1: E1.51, U$3.51
GP111_SPI_2_FS2: E2.51, U$1.51
GP111_SPI_2_FS3: E3.51, U$2.51
GP111_SPI_2_FS4: E4.51, U$4.51
GP111_SPI_2_FS5: E5.51, U$5.51
GP111_SPI_2_FS6: E6.51, U$6.51
GP111_SPI_2_FS7: E7.51, U$7.51
GP111_SPI_2_FS8: E8.51, U$8.51
GP114_SPI_2_RXD: E1.59, U$3.59
GP114_SPI_2_RXD1: E2.59, U$1.59
GP114_SPI_2_RXD2: E3.59, U$2.59
GP114_SPI_2_RXD3: E4.59, U$4.59
GP114_SPI_2_RXD4: E5.59, U$5.59
GP114_SPI_2_RXD5: E6.59, U$6.59
GP114_SPI_2_RXD6: E7.59, U$7.59
GP114_SPI_2_RXD7: E8.59, U$8.59
GP115_SPI_2_TXD: E1.57, U$3.57
GP115_SPI_2_TXD1: E2.57, U$1.57
GP115_SPI_2_TXD2: E3.57, U$2.57
GP115_SPI_2_TXD3: E4.57, U$4.57
GP115_SPI_2_TXD4: E5.57, U$5.57
GP115_SPI_2_TXD5: E6.57, U$6.57
GP115_SPI_2_TXD6: E7.57, U$7.57
GP115_SPI_2_TXD7: E8.57, U$8.57
GP128_UART_1_CTS: E1.65, U$3.65
GP128_UART_1_CTS1: E2.65, U$1.65
GP128_UART_1_CTS2: E3.65, U$2.65
GP128_UART_1_CTS3: E4.65, U$4.65
GP128_UART_1_CTS4: E5.65, U$5.65
GP128_UART_1_CTS5: E6.65, U$6.65
GP128_UART_1_CTS6: E7.65, U$7.65
GP128_UART_1_CTS7: E8.65, U$8.65
GP129_UART_1_RTS: E1.63, U$3.63
GP129_UART_1_RTS1: E2.63, U$1.63
GP129_UART_1_RTS2: E3.63, U$2.63
GP129_UART_1_RTS3: E4.63, U$4.63
GP129_UART_1_RTS4: E5.63, U$5.63
GP129_UART_1_RTS5: E6.63, U$6.63
GP129_UART_1_RTS6: E7.63, U$7.63
GP129_UART_1_RTS7: E8.63, U$8.63
GP130_UART_1_RX: E1.61, U1.5, U$3.61
GP130_UART_1_RX1: E2.61, U3.5, U$1.61
GP130_UART_1_RX2: E3.61, U6.5, U$2.61
GP130_UART_1_RX3: E4.61, U8.5, U$4.61
GP130_UART_1_RX4: E5.61, U10.5, U$5.61
GP130_UART_1_RX5: E6.61, U12.5, U$6.61
GP130_UART_1_RX6: E7.61, U14.5, U$7.61
GP130_UART_1_RX7: E8.61, U16.5, U$8.61
GP131_UART_1_TX: E1.46, U1.4, U$3.46
GP131_UART_1_TX1: E2.46, U3.4, U$1.46
GP131_UART_1_TX2: E3.46, U6.4, U$2.46
GP131_UART_1_TX3: E4.46, U8.4, U$4.46
GP131_UART_1_TX4: E5.46, U10.4, U$5.46
GP131_UART_1_TX5: E6.46, U12.4, U$6.46
GP131_UART_1_TX6: E7.46, U14.4, U$7.46
GP131_UART_1_TX7: E8.46, U16.4, U$8.46
GP134_UART_2_RX: E1.22, U1.3, U$3.22
GP134_UART_2_RX1: E2.22, U3.3, U$1.22
GP134_UART_2_RX2: E3.22, U6.3, U$2.22
GP134_UART_2_RX3: E4.22, U8.3, U$4.22
GP134_UART_2_RX4: E5.22, U10.3, U$5.22
GP134_UART_2_RX5: E6.22, U12.3, U$6.22
GP134_UART_2_RX6: E7.22, U14.3, U$7.22
GP134_UART_2_RX7: E8.22, U16.3, U$8.22
GP135_UART_2_TX: E1.27, U1.2, U$3.27
GP135_UART_2_TX1: E2.27, U3.2, U$1.27
GP135_UART_2_TX2: E3.27, U6.2, U$2.27
GP135_UART_2_TX3: E4.27, U8.2, U$4.27
GP135_UART_2_TX4: E5.27, U10.2, U$5.27
GP135_UART_2_TX5: E6.27, U12.2, U$6.27
GP135_UART_2_TX6: E7.27, U14.2, U$7.27
GP135_UART_2_TX7: E8.27, U16.2, U$8.27
GP165: E1.25, U$3.25
GP182_PWM1: E2.37, U$1.37
GP182_PWM2: E1.37, U$3.37
GP182_PWM3: E3.37, U$2.37
GP182_PWM4: E4.37, U$4.37
GP182_PWM5: E5.37, U$5.37
GP182_PWM6: E6.37, U$6.37
GP182_PWM7: E7.37, U$7.37
GP182_PWM8: E8.37, U$8.37
GP183_PWM1: E2.39, U$1.39
GP183_PWM2: E3.39, U$2.39
GP183_PWM3: E1.39, U$3.39
GP183_PWM4: E4.39, U$4.39
GP183_PWM5: E5.39, U$5.39
GP183_PWM6: E6.39, U$6.39
GP183_PWM7: E7.39, U$7.39
GP183_PWM8: E8.39, U$8.39
MSIC_SLP_CLK: E1.7, U$3.7
MSIC_SLP_CLK1: E2.7, U$1.7
MSIC_SLP_CLK2: E3.7, U$2.7
MSIC_SLP_CLK3: E4.7, U$4.7
MSIC_SLP_CLK4: E5.7, U$5.7
MSIC_SLP_CLK5: E6.7, U$6.7
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

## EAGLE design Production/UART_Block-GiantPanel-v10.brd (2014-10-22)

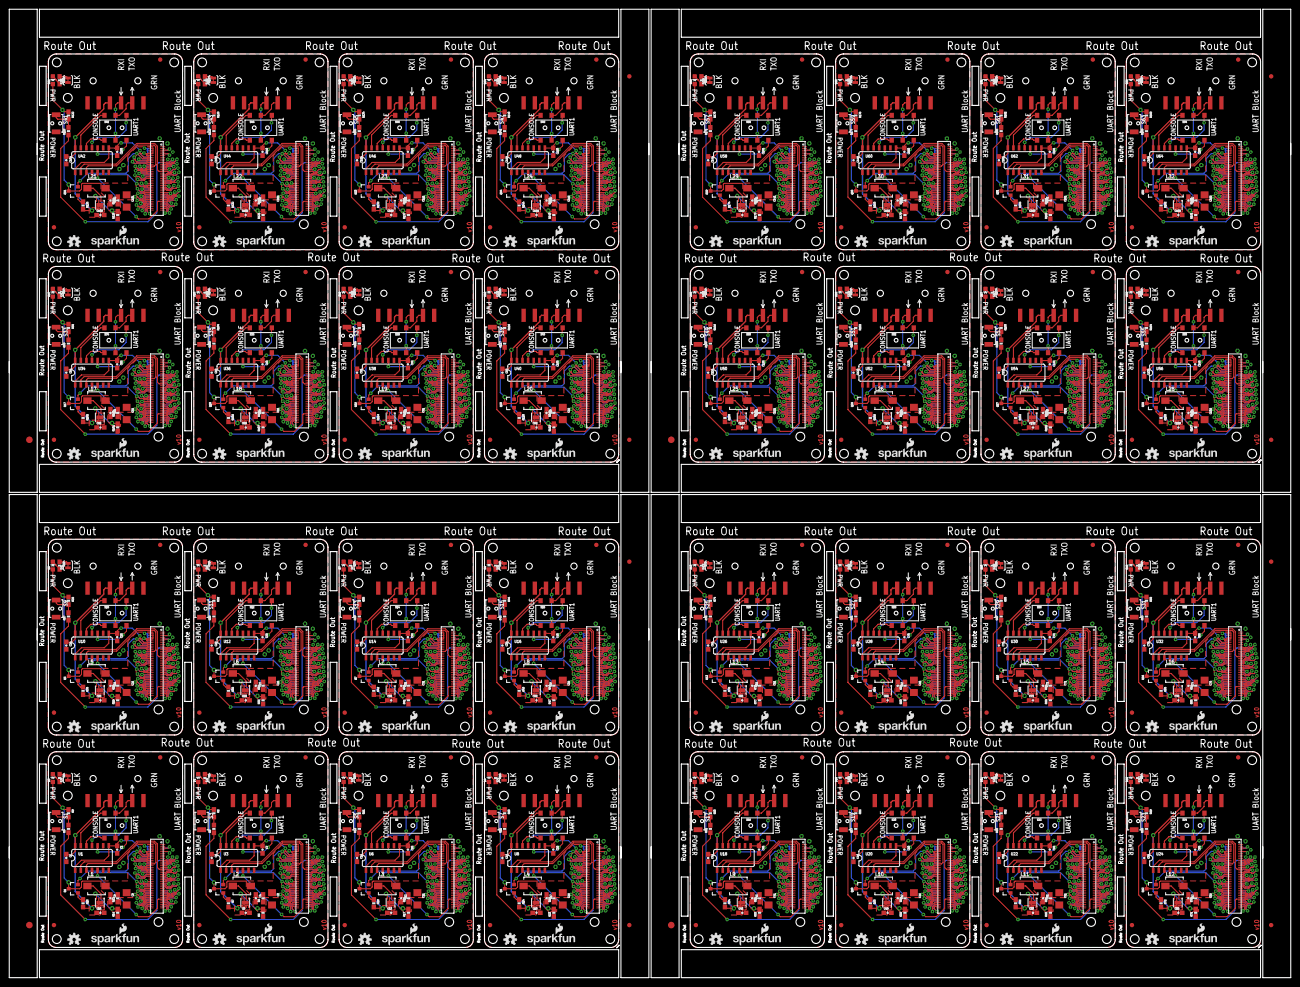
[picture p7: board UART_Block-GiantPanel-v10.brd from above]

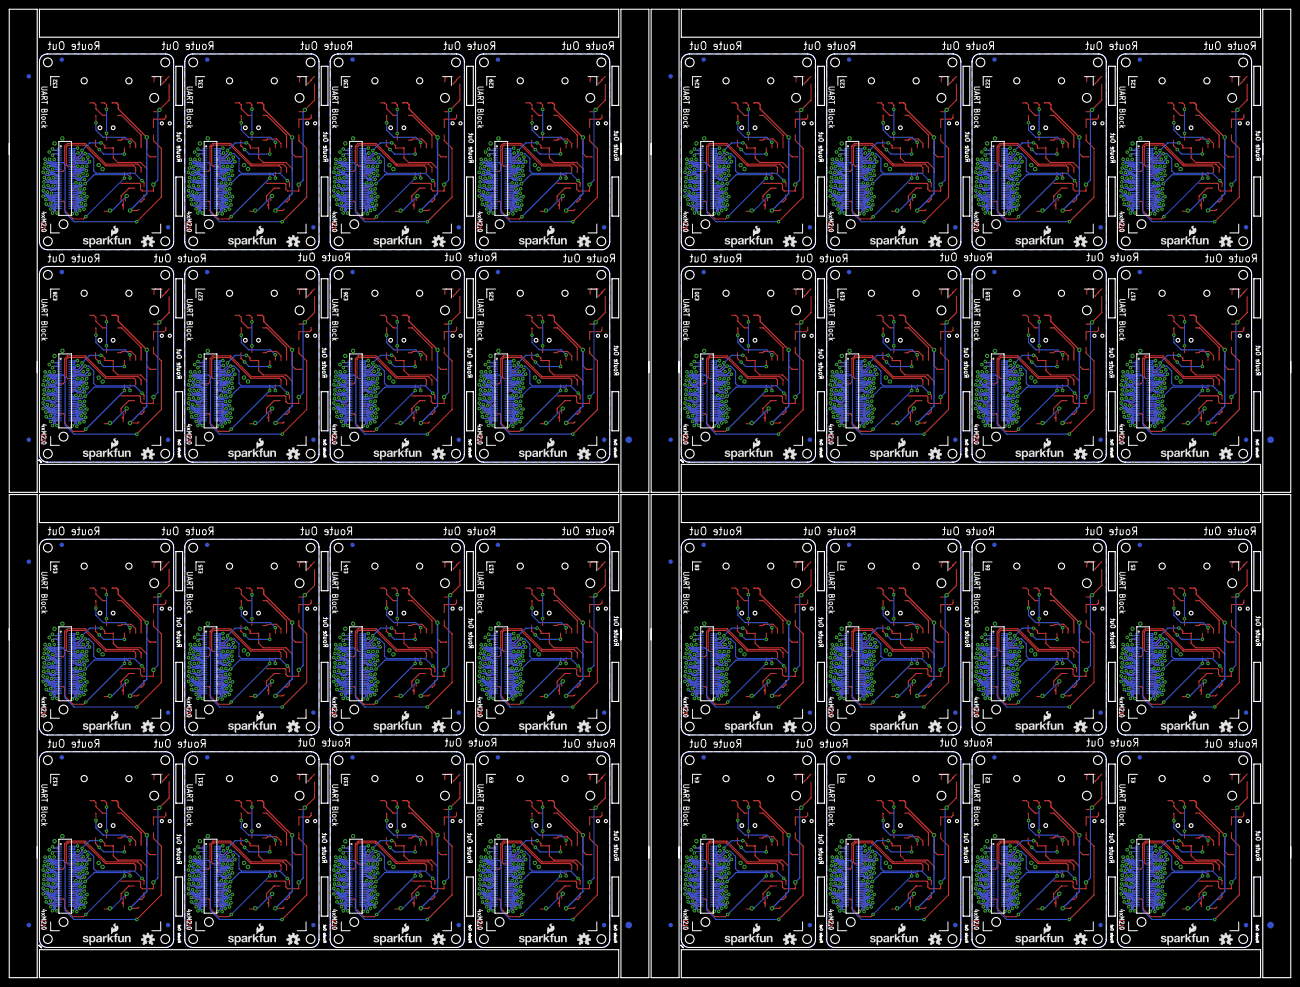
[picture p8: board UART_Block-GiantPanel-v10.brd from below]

Board: 2 copper layers, 291.1 x 220.0 mm, 984 parts (204 on the bottom side), 2272 nets.

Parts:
C1, C2, C6, C7, C14, C15, C19, C20, C24, C25, C29, C30, C34, C35, C39, C40, C44, C45, C49, C50, C54, C55, C59, C60, C64, C65, C69, C70, C74, C75, C79, C80, C84, C85, C89, C90, C94, C95, C99, C100, C104, C105, C109, C110, C114, C115, C119, C120, C124, C125, C129, C130, C134, C135, C139, C140, C144, C145, C149, C150, C154, C155, C159, C160: 0.1uF; 0603-CAP
C3, C8, C11, C16, C21, C26, C31, C36, C41, C46, C51, C56, C61, C66, C71, C76, C81, C86, C91, C96, C101, C106, C111, C116, C121, C126, C131, C136, C141, C146, C151, C156: 10uF; 1206
C4, C9, C12, C17, C22, C27, C32, C37, C42, C47, C52, C57, C62, C67, C72, C77, C82, C87, C92, C97, C102, C107, C112, C117, C122, C127, C132, C137, C142, C147, C152, C157: 47pF; 0603-CAP
C5, C10, C13, C18, C23, C28, C33, C38, C43, C48, C53, C58, C63, C68, C73, C78, C83, C88, C93, C98, C103, C108, C113, C118, C123, C128, C133, C138, C143, C148, C153, C158: 4.7uF; 0603-CAP
D1, D2, D3, D4, D5, D6, D7, D8, D9, D10, D11, D12, D13, D14, D15, D16, D17, D18, D19, D20, D21, D22, D23, D24, D25, D26, D27, D28, D29, D30, D31, D32: BLUE; LED-0603
E1, E2, E3, E4, E5, E6, E7, E8, E9, E10, E11, E12, E13, E14, E15, E16, E17, E18, E19, E20, E21, E22, E23, E24, E25, E26, E27, E28, E29, E30, E31, E32: EDISON_CONNECTOR_FULLMOUNTING_HOLES; EDISON_DAUGHTER
E$1, E$2, E$9, E$10, E$15, E$16, E$21, E$22: FIDUCIAL-1.5X3
E$3, E$4, E$5, E$6, E$7, E$8, E$11, E$12, E$13, E$14, E$17, E$18, E$19, E$20, E$23, E$24: FIDUCIAL-1X2
FID1, FID2, FID3, FID4, FID5, FID6, FID7, FID8, FID9, FID10, FID11, FID12, FID13, FID14, FID15, FID16, FID17, FID18, FID19, FID20, FID21, FID22, FID23, FID24, FID25, FID26, FID27, FID28, FID29, FID30, FID31, FID32, FID33, FID34, FID35, FID36, FID37, FID38, FID39, FID40, FID41, FID42, FID43, FID44, FID45, FID46, FID47, FID48, FID49, FID50, FID51, FID52, FID53, FID54, FID55, FID56, FID57, FID58, FID59, FID60, FID61, FID62, FID63, FID64, FID65, FID66, FID67, FID68, FID69, FID70, FID71, FID72, FID73, FID74, FID75, FID76, FID77, FID78, FID79, FID80, FID81, FID82, FID83, FID84, FID85, FID86, FID87, FID88, FID89, FID90, FID91, FID92, FID93, FID94, FID95, FID96, FID97, FID98, FID99, FID100, FID101, FID102, FID103, FID104, FID105, FID106, FID107, FID108, FID109, FID110, FID111, FID112, FID113, FID114, FID115, FID116, FID117, FID118, FID119, FID120, FID121, FID122, FID123, FID124, FID125, FID126, FID127, FID128: FIDUCIAL1X2; FIDUCIAL-1X2
JP1, JP2, JP3, JP4, JP5, JP6, JP7, JP8, JP9, JP10, JP11, JP12, JP13, JP14, JP15, JP16, JP17, JP18, JP19, JP20, JP21, JP22, JP23, JP24, JP25, JP26, JP27, JP28, JP29, JP30, JP31, JP32: 1X06-SMD
L1, L2, L3, L4, L5, L6, L7, L8, L9, L10, L11, L12, L13, L14, L15, L16, L17, L18, L19, L20, L21, L22, L23, L24, L25, L26, L27, L28, L29, L30, L31, L32: INDUCTOR-SRP4020
LOGO1, LOGO3, LOGO6, LOGO7, LOGO10, LOGO11, LOGO14, LOGO15, LOGO18, LOGO19, LOGO22, LOGO23, LOGO26, LOGO27, LOGO30, LOGO31, LOGO34, LOGO35, LOGO38, LOGO39, LOGO42, LOGO43, LOGO46, LOGO47, LOGO50, LOGO51, LOGO54, LOGO55, LOGO58, LOGO59, LOGO62, LOGO63, LOGO66, LOGO67, LOGO70, LOGO71, LOGO74, LOGO75, LOGO78, LOGO79, LOGO82, LOGO83, LOGO86, LOGO87, LOGO90, LOGO91, LOGO94, LOGO95, LOGO98, LOGO99, LOGO102, LOGO103, LOGO106, LOGO107, LOGO110, LOGO111, LOGO114, LOGO115, LOGO118, LOGO119, LOGO122, LOGO123, LOGO126, LOGO127: SFE_LOGO_NAME_FLAME.1_INCH; SFE_LOGO_NAME_FLAME_.1
LOGO2, LOGO4, LOGO5, LOGO8, LOGO9, LOGO12, LOGO13, LOGO16, LOGO17, LOGO20, LOGO21, LOGO24, LOGO25, LOGO28, LOGO29, LOGO32, LOGO33, LOGO36, LOGO37, LOGO40, LOGO41, LOGO44, LOGO45, LOGO48, LOGO49, LOGO52, LOGO53, LOGO56, LOGO57, LOGO60, LOGO61, LOGO64, LOGO65, LOGO68, LOGO69, LOGO72, LOGO73, LOGO76, LOGO77, LOGO80, LOGO81, LOGO84, LOGO85, LOGO88, LOGO89, LOGO92, LOGO93, LOGO96, LOGO97, LOGO100, LOGO101, LOGO104, LOGO105, LOGO108, LOGO109, LOGO112, LOGO113, LOGO116, LOGO117, LOGO120, LOGO121, LOGO124, LOGO125, LOGO128: OSHW-LOGOS; OSHW-LOGO-S
Q1, Q2, Q3, Q4, Q5, Q6, Q7, Q8, Q9, Q10, Q11, Q12, Q13, Q14, Q15, Q16, Q17, Q18, Q19, Q20, Q21, Q22, Q23, Q24, Q25, Q26, Q27, Q28, Q29, Q30, Q31, Q32: BSS138; SOT23-3
R1, R5, R7, R10, R15, R18, R19, R24, R25, R30, R31, R36, R37, R42, R43, R48, R49, R54, R55, R60, R61, R66, R67, R72, R73, R78, R79, R84, R85, R90, R91, R96, R97, R102, R103, R108, R109, R114, R115, R120, R121, R126, R127, R132, R133, R138, R139, R144, R145, R150, R151, R156, R157, R162, R163, R168, R169, R174, R175, R180, R181, R186, R187, R192: 1K; 0603-RES
R2, R8, R11, R20, R26, R32, R38, R44, R50, R56, R62, R68, R74, R80, R86, R92, R98, R104, R110, R116, R122, R128, R134, R140, R146, R152, R158, R164, R170, R176, R182, R188: 10K; 0603-RES
R3, R9, R12, R21, R27, R33, R39, R45, R51, R57, R63, R69, R75, R81, R87, R93, R99, R105, R111, R117, R123, R129, R135, R141, R147, R153, R159, R165, R171, R177, R183, R189: 22; 0603-RES
R4, R13, R16, R22, R28, R34, R40, R46, R52, R58, R64, R70, R76, R82, R88, R94, R100, R106, R112, R118, R124, R130, R136, R142, R148, R154, R160, R166, R172, R178, R184, R190: 680k; 0603-RES
R6, R14, R17, R23, R29, R35, R41, R47, R53, R59, R65, R71, R77, R83, R89, R95, R101, R107, R113, R119, R125, R131, R137, R143, R149, R155, R161, R167, R173, R179, R185, R191: 120k; 0603-RES
S1, S3, S5, S7, S9, S11, S13, S15, S17, S19, S21, S23, S25, S27, S29, S31, S33, S35, S37, S39, S41, S43, S45, S47, S49, S51, S53, S55, S57, S59, S61, S63: POWER; TACTILE_SWITCH-SMD-RIGHT-ANGLE
S2, S4, S6, S8, S10, S12, S14, S16, S18, S20, S22, S24, S26, S28, S30, S32, S34, S36, S38, S40, S42, S44, S46, S48, S50, S52, S54, S56, S58, S60, S62, S64: DPDT; AYZ0202
SJ1, SJ2, SJ3, SJ4, SJ5, SJ6, SJ7, SJ8, SJ9, SJ10, SJ11, SJ12, SJ13, SJ14, SJ15, SJ16, SJ17, SJ18, SJ19, SJ20, SJ21, SJ22, SJ23, SJ24, SJ25, SJ26, SJ27, SJ28, SJ29, SJ30, SJ31, SJ32: JUMPER-PAD-2-NC_BY_TRACE; PAD-JUMPER-2-NC_BY_TRACE_YES_SILK
U1, U3, U6, U8, U10, U12, U14, U16, U18, U20, U22, U24, U26, U28, U30, U32, U34, U36, U38, U40, U42, U44, U46, U48, U50, U52, U54, U56, U58, U60, U62, U64: SO14
U2, U4, U5, U7, U9, U11, U13, U15, U17, U19, U21, U23, U25, U27, U29, U31, U33, U35, U37, U39, U41, U43, U45, U47, U49, U51, U53, U55, U57, U59, U61, U63: TPS62065; WSON-8-PAD
U$1, U$2, U$3, U$4, U$5, U$6, U$7, U$8, U$9, U$10, U$11, U$12, U$13, U$14, U$15, U$16, U$17, U$18, U$19, U$20, U$21, U$22, U$23, U$24, U$25, U$26, U$27, U$28, U$29, U$30, U$31, U$32: EDISON_CONNECTOR_FULLHEADER; DF40C-70DP-0.4(51)

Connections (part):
1.8V: C2.1, E1.12, U1.1, U1.8, U$3.12
1.8V1: C7.1, E2.12, U3.1, U3.8, U$1.12
1.8V2: C15.1, E3.12, U6.1, U6.8, U$2.12
1.8V3: C20.1, E4.12, U8.1, U8.8, U$4.12
1.8V4: C25.1, E5.12, U10.1, U10.8, U$5.12
1.8V5: C30.1, E6.12, U12.1, U12.8, U$6.12
1.8V6: C35.1, E7.12, U14.1, U14.8, U$7.12
1.8V7: C40.1, E8.12, U16.1, U16.8, U$8.12
1.8V8: C45.1, E9.12, U18.1, U18.8, U$9.12
1.8V9: C50.1, E10.12, U20.1, U20.8, U$10.12
1.8V10: C55.1, E11.12, U22.1, U22.8, U$11.12
1.8V11: C60.1, E12.12, U24.1, U24.8, U$12.12
1.8V12: C65.1, E13.12, U26.1, U26.8, U$13.12
1.8V13: C70.1, E14.12, U28.1, U28.8, U$14.12
1.8V14: C75.1, E15.12, U30.1, U30.8, U$15.12
1.8V15: C80.1, E16.12, U32.1, U32.8, U$16.12
1.8V16: C85.1, E17.12, U34.1, U34.8, U$17.12
1.8V17: C90.1, E18.12, U36.1, U36.8, U$18.12
1.8V18: C95.1, E19.12, U38.1, U38.8, U$19.12
1.8V19: C100.1, E20.12, U40.1, U40.8, U$20.12
1.8V20: C105.1, E21.12, U42.1, U42.8, U$21.12
1.8V21: C110.1, E22.12, U44.1, U44.8, U$22.12
1.8V22: C115.1, E23.12, U46.1, U46.8, U$23.12
1.8V23: C120.1, E24.12, U48.1, U48.8, U$24.12
1.8V24: C125.1, E25.12, U50.1, U50.8, U$25.12
1.8V25: C130.1, E26.12, U52.1, U52.8, U$26.12
1.8V26: C135.1, E27.12, U54.1, U54.8, U$27.12
1.8V27: C140.1, E28.12, U56.1, U56.8, U$28.12
1.8V28: C145.1, E29.12, U58.1, U58.8, U$29.12
1.8V29: C150.1, E30.12, U60.1, U60.8, U$30.12
1.8V30: C155.1, E31.12, U62.1, U62.8, U$31.12
1.8V31: C160.1, E32.12, U64.1, U64.8, U$32.12
3.3V: E1.8, E1.10, U$3.8, U$3.10
3.3V1: E2.8, E2.10, U$1.8, U$1.10
3.3V2: E3.8, E3.10, U$2.8, U$2.10
3.3V3: E4.8, E4.10, U$4.8, U$4.10
3.3V4: E5.8, E5.10, U$5.8, U$5.10
3.3V5: E6.8, E6.10, U$6.8, U$6.10
3.3V6: E7.8, E7.10, U$7.8, U$7.10
3.3V7: E8.8, E8.10, U$8.8, U$8.10
3.3V8: E9.8, E9.10, U$9.8, U$9.10
3.3V9: E10.8, E10.10, U$10.8, U$10.10
3.3V10: E11.8, E11.10, U$11.8, U$11.10
3.3V11: E12.8, E12.10, U$12.8, U$12.10
3.3V12: E13.8, E13.10, U$13.8, U$13.10
3.3V13: E14.8, E14.10, U$14.8, U$14.10
3.3V14: E15.8, E15.10, U$15.8, U$15.10
3.3V15: E16.8, E16.10, U$16.8, U$16.10
3.3V16: E17.8, E17.10, U$17.8, U$17.10
3.3V17: E18.8, E18.10, U$18.8, U$18.10
3.3V18: E19.8, E19.10, U$19.8, U$19.10
3.3V19: E20.8, E20.10, U$20.8, U$20.10
3.3V20: E21.8, E21.10, U$21.8, U$21.10
3.3V21: E22.8, E22.10, U$22.8, U$22.10
3.3V22: E23.8, E23.10, U$23.8, U$23.10
3.3V23: E24.8, E24.10, U$24.8, U$24.10
3.3V24: E25.8, E25.10, U$25.8, U$25.10
3.3V25: E26.8, E26.10, U$26.8, U$26.10
3.3V26: E27.8, E27.10, U$27.8, U$27.10
3.3V27: E28.8, E28.10, U$28.8, U$28.10
3.3V28: E29.8, E29.10, U$29.8, U$29.10
3.3V29: E30.8, E30.10, U$30.8, U$30.10
3.3V30: E31.8, E31.10, U$31.8, U$31.10
3.3V31: E32.8, E32.10, U$32.8, U$32.10
DCIN: E1.14, Q1.2, U$3.14
DCIN1: E2.14, Q2.2, U$1.14
DCIN2: E3.14, Q3.2, U$2.14
DCIN3: E4.14, Q4.2, U$4.14
DCIN4: E5.14, Q5.2, U$5.14
DCIN5: E6.14, Q6.2, U$6.14
DCIN6: E7.14, Q7.2, U$7.14
DCIN7: E8.14, Q8.2, U$8.14
DCIN8: E9.14, Q9.2, U$9.14
DCIN9: E10.14, Q10.2, U$10.14
DCIN10: E11.14, Q11.2, U$11.14
DCIN11: E12.14, Q12.2, U$12.14
DCIN12: E13.14, Q13.2, U$13.14
DCIN13: E14.14, Q14.2, U$14.14
DCIN14: E15.14, Q15.2, U$15.14
DCIN15: E16.14, Q16.2, U$16.14
DCIN16: E17.14, Q17.2, U$17.14
DCIN17: E18.14, Q18.2, U$18.14
DCIN18: E19.14, Q19.2, U$19.14
DCIN19: E20.14, Q20.2, U$20.14
DCIN20: E21.14, Q21.2, U$21.14
DCIN21: E22.14, Q22.2, U$22.14
DCIN22: E23.14, Q23.2, U$23.14
DCIN23: E24.14, Q24.2, U$24.14
DCIN24: E25.14, Q25.2, U$25.14
DCIN25: E26.14, Q26.2, U$26.14
DCIN26: E27.14, Q27.2, U$27.14
DCIN27: E28.14, Q28.2, U$28.14
DCIN28: E29.14, Q29.2, U$29.14
DCIN29: E30.14, Q30.2, U$30.14
DCIN30: E31.14, Q31.2, U$31.14
DCIN31: E32.14, Q32.2, U$32.14
FAULT: E1.19, U$3.19
FAULT1: E2.19, U$1.19
FAULT2: E3.19, U$2.19
FAULT3: E4.19, U$4.19
FAULT4: E5.19, U$5.19
FAULT5: E6.19, U$6.19
FAULT6: E7.19, U$7.19
FAULT7: E8.19, U$8.19
FAULT8: E9.19, U$9.19
FAULT9: E10.19, U$10.19
FAULT10: E11.19, U$11.19
FAULT11: E12.19, U$12.19
FAULT12: E13.19, U$13.19
FAULT13: E14.19, U$14.19
FAULT14: E15.19, U$15.19
FAULT15: E16.19, U$16.19
FAULT16: E17.19, U$17.19
FAULT17: E18.19, U$18.19
FAULT18: E19.19, U$19.19
FAULT19: E20.19, U$20.19
FAULT20: E21.19, U$21.19
FAULT21: E22.19, U$22.19
FAULT22: E23.19, U$23.19
FAULT23: E24.19, U$24.19
FAULT24: E25.19, U$25.19
FAULT25: E26.19, U$26.19
FAULT26: E27.19, U$27.19
FAULT27: E28.19, U$28.19
FAULT28: E29.19, U$29.19
FAULT29: E30.19, U$30.19
FAULT30: E31.19, U$31.19
FAULT31: E32.19, U$32.19
FW_RCVR: E1.69, U$3.69
FW_RCVR1: E2.69, U$1.69
FW_RCVR2: E3.69, U$2.69
FW_RCVR3: E4.69, U$4.69
FW_RCVR4: E5.69, U$5.69
FW_RCVR5: E6.69, U$6.69
FW_RCVR6: E7.69, U$7.69
FW_RCVR7: E8.69, U$8.69
FW_RCVR8: E9.69, U$9.69
FW_RCVR9: E10.69, U$10.69
FW_RCVR10: E11.69, U$11.69
FW_RCVR11: E12.69, U$12.69
FW_RCVR12: E13.69, U$13.69
FW_RCVR13: E14.69, U$14.69
FW_RCVR14: E15.69, U$15.69
FW_RCVR15: E16.69, U$16.69
FW_RCVR16: E17.69, U$17.69
FW_RCVR17: E18.69, U$18.69
FW_RCVR18: E19.69, U$19.69
FW_RCVR19: E20.69, U$20.69
FW_RCVR20: E21.69, U$21.69
FW_RCVR21: E22.69, U$22.69
FW_RCVR22: E23.69, U$23.69
FW_RCVR23: E24.69, U$24.69
FW_RCVR24: E25.69, U$25.69
FW_RCVR25: E26.69, U$26.69
FW_RCVR26: E27.69, U$27.69
FW_RCVR27: E28.69, U$28.69
FW_RCVR28: E29.69, U$29.69
FW_RCVR29: E30.69, U$30.69
FW_RCVR30: E31.69, U$31.69
FW_RCVR31: E32.69, U$32.69
GND: C1.2, C2.2, C8.2, C10.2, E1.1, E1.5, E1.9, E1.11, E1.13, E1.15, JP2.5, JP2.6, R14.1, S1.2, SJ3.1, U1.7, U4.1, U4.3, U4.6, U4.PAD, U$3.1, U$3.5, U$3.9, U$3.11, U$3.13, U$3.15
GND1: C3.2, C5.2, C6.2, C7.2, E2.1, E2.5, E2.9, E2.11, E2.13, E2.15, JP1.5, JP1.6, R6.1, S3.2, SJ1.1, U2.1, U2.3, U2.6, U2.PAD, U3.7, U$1.1, U$1.5, U$1.9, U$1.11, U$1.13, U$1.15
GND2: C11.2, C13.2, C14.2, C15.2, E3.1, E3.5, E3.9, E3.11, E3.13, E3.15, JP3.5, JP3.6, R17.1, S5.2, SJ2.1, U5.1, U5.3, U5.6, U5.PAD, U6.7, U$2.1, U$2.5, U$2.9, U$2.11, U$2.13, U$2.15
GND3: C16.2, C18.2, C19.2, C20.2, E4.1, E4.5, E4.9, E4.11, E4.13, E4.15, JP4.5, JP4.6, R23.1, S7.2, SJ4.1, U7.1, U7.3, U7.6, U7.PAD, U8.7, U$4.1, U$4.5, U$4.9, U$4.11, U$4.13, U$4.15
GND4: C21.2, C23.2, C24.2, C25.2, E5.1, E5.5, E5.9, E5.11, E5.13, E5.15, JP5.5, JP5.6, R29.1, S9.2, SJ5.1, U9.1, U9.3, U9.6, U9.PAD, U10.7, U$5.1, U$5.5, U$5.9, U$5.11, U$5.13, U$5.15
GND5: C26.2, C28.2, C29.2, C30.2, E6.1, E6.5, E6.9, E6.11, E6.13, E6.15, JP6.5, JP6.6, R35.1, S11.2, SJ6.1, U11.1, U11.3, U11.6, U11.PAD, U12.7, U$6.1, U$6.5, U$6.9, U$6.11, U$6.13, U$6.15
GND6: C31.2, C33.2, C34.2, C35.2, E7.1, E7.5, E7.9, E7.11, E7.13, E7.15, JP7.5, JP7.6, R41.1, S13.2, SJ7.1, U13.1, U13.3, U13.6, U13.PAD, U14.7, U$7.1, U$7.5, U$7.9, U$7.11, U$7.13, U$7.15
GND7: C36.2, C38.2, C39.2, C40.2, E8.1, E8.5, E8.9, E8.11, E8.13, E8.15, JP8.5, JP8.6, R47.1, S15.2, SJ8.1, U15.1, U15.3, U15.6, U15.PAD, U16.7, U$8.1, U$8.5, U$8.9, U$8.11, U$8.13, U$8.15
GND8: C41.2, C43.2, C44.2, C45.2, E9.1, E9.5, E9.9, E9.11, E9.13, E9.15, JP9.5, JP9.6, R53.1, S17.2, SJ9.1, U17.1, U17.3, U17.6, U17.PAD, U18.7, U$9.1, U$9.5, U$9.9, U$9.11, U$9.13, U$9.15
GND9: C46.2, C48.2, C49.2, C50.2, E10.1, E10.5, E10.9, E10.11, E10.13, E10.15, JP10.5, JP10.6, R59.1, S19.2, SJ10.1, U19.1, U19.3, U19.6, U19.PAD, U20.7, U$10.1, U$10.5, U$10.9, U$10.11, U$10.13, U$10.15
GND10: C51.2, C53.2, C54.2, C55.2, E11.1, E11.5, E11.9, E11.11, E11.13, E11.15, JP11.5, JP11.6, R65.1, S21.2, SJ11.1, U21.1, U21.3, U21.6, U21.PAD, U22.7, U$11.1, U$11.5, U$11.9, U$11.11, U$11.13, U$11.15
GND11: C56.2, C58.2, C59.2, C60.2, E12.1, E12.5, E12.9, E12.11, E12.13, E12.15, JP12.5, JP12.6, R71.1, S23.2, SJ12.1, U23.1, U23.3, U23.6, U23.PAD, U24.7, U$12.1, U$12.5, U$12.9, U$12.11, U$12.13, U$12.15
GND12: C61.2, C63.2, C64.2, C65.2, E13.1, E13.5, E13.9, E13.11, E13.13, E13.15, JP13.5, JP13.6, R77.1, S25.2, SJ13.1, U25.1, U25.3, U25.6, U25.PAD, U26.7, U$13.1, U$13.5, U$13.9, U$13.11, U$13.13, U$13.15
GND13: C66.2, C68.2, C69.2, C70.2, E14.1, E14.5, E14.9, E14.11, E14.13, E14.15, JP14.5, JP14.6, R83.1, S27.2, SJ14.1, U27.1, U27.3, U27.6, U27.PAD, U28.7, U$14.1, U$14.5, U$14.9, U$14.11, U$14.13, U$14.15
GND14: C71.2, C73.2, C74.2, C75.2, E15.1, E15.5, E15.9, E15.11, E15.13, E15.15, JP15.5, JP15.6, R89.1, S29.2, SJ15.1, U29.1, U29.3, U29.6, U29.PAD, U30.7, U$15.1, U$15.5, U$15.9, U$15.11, U$15.13, U$15.15
GND15: C76.2, C78.2, C79.2, C80.2, E16.1, E16.5, E16.9, E16.11, E16.13, E16.15, JP16.5, JP16.6, R95.1, S31.2, SJ16.1, U31.1, U31.3, U31.6, U31.PAD, U32.7, U$16.1, U$16.5, U$16.9, U$16.11, U$16.13, U$16.15
GND16: C81.2, C83.2, C84.2, C85.2, E17.1, E17.5, E17.9, E17.11, E17.13, E17.15, JP17.5, JP17.6, R101.1, S33.2, SJ17.1, U33.1, U33.3, U33.6, U33.PAD, U34.7, U$17.1, U$17.5, U$17.9, U$17.11, U$17.13, U$17.15
GND17: C86.2, C88.2, C89.2, C90.2, E18.1, E18.5, E18.9, E18.11, E18.13, E18.15, JP18.5, JP18.6, R107.1, S35.2, SJ18.1, U35.1, U35.3, U35.6, U35.PAD, U36.7, U$18.1, U$18.5, U$18.9, U$18.11, U$18.13, U$18.15
GND18: C91.2, C93.2, C94.2, C95.2, E19.1, E19.5, E19.9, E19.11, E19.13, E19.15, JP19.5, JP19.6, R113.1, S37.2, SJ19.1, U37.1, U37.3, U37.6, U37.PAD, U38.7, U$19.1, U$19.5, U$19.9, U$19.11, U$19.13, U$19.15
GND19: C96.2, C98.2, C99.2, C100.2, E20.1, E20.5, E20.9, E20.11, E20.13, E20.15, JP20.5, JP20.6, R119.1, S39.2, SJ20.1, U39.1, U39.3, U39.6, U39.PAD, U40.7, U$20.1, U$20.5, U$20.9, U$20.11, U$20.13, U$20.15
GND20: C101.2, C103.2, C104.2, C105.2, E21.1, E21.5, E21.9, E21.11, E21.13, E21.15, JP21.5, JP21.6, R125.1, S41.2, SJ21.1, U41.1, U41.3, U41.6, U41.PAD, U42.7, U$21.1, U$21.5, U$21.9, U$21.11, U$21.13, U$21.15
GND21: C106.2, C108.2, C109.2, C110.2, E22.1, E22.5, E22.9, E22.11, E22.13, E22.15, JP22.5, JP22.6, R131.1, S43.2, SJ22.1, U43.1, U43.3, U43.6, U43.PAD, U44.7, U$22.1, U$22.5, U$22.9, U$22.11, U$22.13, U$22.15
GND22: C111.2, C113.2, C114.2, C115.2, E23.1, E23.5, E23.9, E23.11, E23.13, E23.15, JP23.5, JP23.6, R137.1, S45.2, SJ23.1, U45.1, U45.3, U45.6, U45.PAD, U46.7, U$23.1, U$23.5, U$23.9, U$23.11, U$23.13, U$23.15
GND23: C116.2, C118.2, C119.2, C120.2, E24.1, E24.5, E24.9, E24.11, E24.13, E24.15, JP24.5, JP24.6, R143.1, S47.2, SJ24.1, U47.1, U47.3, U47.6, U47.PAD, U48.7, U$24.1, U$24.5, U$24.9, U$24.11, U$24.13, U$24.15
GND24: C121.2, C123.2, C124.2, C125.2, E25.1, E25.5, E25.9, E25.11, E25.13, E25.15, JP25.5, JP25.6, R149.1, S49.2, SJ25.1, U49.1, U49.3, U49.6, U49.PAD, U50.7, U$25.1, U$25.5, U$25.9, U$25.11, U$25.13, U$25.15
GND25: C126.2, C128.2, C129.2, C130.2, E26.1, E26.5, E26.9, E26.11, E26.13, E26.15, JP26.5, JP26.6, R155.1, S51.2, SJ26.1, U51.1, U51.3, U51.6, U51.PAD, U52.7, U$26.1, U$26.5, U$26.9, U$26.11, U$26.13, U$26.15
GND26: C131.2, C133.2, C134.2, C135.2, E27.1, E27.5, E27.9, E27.11, E27.13, E27.15, JP27.5, JP27.6, R161.1, S53.2, SJ27.1, U53.1, U53.3, U53.6, U53.PAD, U54.7, U$27.1, U$27.5, U$27.9, U$27.11, U$27.13, U$27.15
GND27: C136.2, C138.2, C139.2, C140.2, E28.1, E28.5, E28.9, E28.11, E28.13, E28.15, JP28.5, JP28.6, R167.1, S55.2, SJ28.1, U55.1, U55.3, U55.6, U55.PAD, U56.7, U$28.1, U$28.5, U$28.9, U$28.11, U$28.13, U$28.15
GND28: C141.2, C143.2, C144.2, C145.2, E29.1, E29.5, E29.9, E29.11, E29.13, E29.15, JP29.5, JP29.6, R173.1, S57.2, SJ29.1, U57.1, U57.3, U57.6, U57.PAD, U58.7, U$29.1, U$29.5, U$29.9, U$29.11, U$29.13, U$29.15
GND29: C146.2, C148.2, C149.2, C150.2, E30.1, E30.5, E30.9, E30.11, E30.13, E30.15, JP30.5, JP30.6, R179.1, S59.2, SJ30.1, U59.1, U59.3, U59.6, U59.PAD, U60.7, U$30.1, U$30.5, U$30.9, U$30.11, U$30.13, U$30.15
GND30: C151.2, C153.2, C154.2, C155.2, E31.1, E31.5, E31.9, E31.11, E31.13, E31.15, JP31.5, JP31.6, R185.1, S61.2, SJ31.1, U61.1, U61.3, U61.6, U61.PAD, U62.7, U$31.1, U$31.5, U$31.9, U$31.11, U$31.13, U$31.15
GND31: C156.2, C158.2, C159.2, C160.2, E32.1, E32.5, E32.9, E32.11, E32.13, E32.15, JP32.5, JP32.6, R191.1, S63.2, SJ32.1, U63.1, U63.3, U63.6, U63.PAD, U64.7, U$32.1, U$32.5, U$32.9, U$32.11, U$32.13, U$32.15
GP1: E2.48, U$1.48
GP2: E2.42, U$1.42
GP3: E2.34, U$1.34
GP4: E2.32, U$1.32
GP5: E2.30, U$1.30
GP6: E2.28, U$1.28
GP7: E2.26, U$1.26
GP8: E2.25, U$1.25
GP9: E2.24, U$1.24
GP10: E3.48, U$2.48
GP11: E3.42, U$2.42
GP12: E3.34, U$2.34
GP12_PWM0: E1.35, U$3.35
GP12_PWM1: E2.35, U$1.35
GP12_PWM2: E3.35, U$2.35
GP12_PWM3: E4.35, U$4.35
GP12_PWM4: E5.35, U$5.35
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

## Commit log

2014-08-08 added boards for basic console. Not ready for review yet
    [Edzzanine_Console_Basic.brd, Edzzanine_Console_Basic.sch]
2014-08-12 finished layout, ready for review
    [Edzzanine_Console_Basic.brd, Edzzanine_Console_Basic.sch]
2014-08-12 sch cleanup
    [Edzzanine_Console_Basic.sch]
2014-08-12 removed Edzzanine from name
    [Edzzanine_Console_Basic.brd]
2014-08-12 fixed rx tx
    [Edzzanine_Console_Basic.brd, Edzzanine_Console_Basic.sch]
2014-08-14 fixed OE to high
    [Edzzanine_Console_Basic.brd, Edzzanine_Console_Basic.sch]
2014-09-24 added DCIN pin added DCIN enable circuit corrected Copper pours corrected name changed names of board and SCH replaced power button updated header footprint added units and cleaned up dimensions
    [UART_Block.brd, UART_Block.sch]
2014-10-16 Rev to 10, fix gnd, pwr, txt
    [UART_Block.brd, UART_Block.sch]
2014-10-17 Fix packages, silk, filter cap.
    [UART_Block.brd, UART_Block.sch]
2014-10-17 Ready for reds Updated and corrected some labels on UART connector. No signal changes. No known to-do items
    [UART_Block.brd, UART_Block.sch]
2014-10-22 corrected jumpers on power supply IC removed thermal relief
    [UART_Block.brd]
2014-10-22 added bottom side fids
    [UART_Block.brd, UART_Block.sch]
2014-10-22 created v10 panels
    [UART_Block-GiantPanel-v10.brd, UART_Block-Panel-v10.brd]
2015-04-01 Updating README and directory names
    [UART_Block-GiantPanel-v10.brd, UART_Block-Panel-v10.brd]

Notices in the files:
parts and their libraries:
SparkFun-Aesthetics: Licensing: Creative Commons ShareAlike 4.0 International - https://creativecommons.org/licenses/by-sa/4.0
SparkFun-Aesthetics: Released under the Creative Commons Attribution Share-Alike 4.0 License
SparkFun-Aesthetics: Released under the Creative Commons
